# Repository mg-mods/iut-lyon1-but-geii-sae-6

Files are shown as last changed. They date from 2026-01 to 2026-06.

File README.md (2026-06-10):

# SAE 6 - Système d'alarme
Repo du projet **SAE 6 "système d'alarme"** réalisé dans le cadre de notre troisième année de BUT GEII à l'IUT Lyon 1.

## Concept initial
Notre projet consiste à développer un système d’alarme domestique complet, prêt à être installé sur une maison.

Les systèmes de surveillance actifs sont des détecteurs d’ouverture de portes et fenêtres ainsi qu’une caméra équipée de reconnaissance faciale à l’entrée.

L’interface utilisateur sera supportée par un M5Stack qui communiquera sans fil, en HF, avec le module central. À ce dernier sont reliés tous les différents composants (capteurs, reconnaissance faciale et alarme). L’interface permettra de verrouiller et déverrouiller le système d’alarme à l’aide d’un code à composer sur l’interface ou d’un badge RFID (à condition que la personne utilisant le badge soit reconnue par la reconnaissance faciale). Lorsqu’une intrusion est détectée, un module d’alarme est déclenché. 

Le module d'alimentation permet, en cas de coupure de courant, d'utiliser l'énergie stockée dans une batterie et de recharger cette dernière une fois le courant rétabli. Ce module d'alimentation est aussi responsable du déclenchement du mode dégradé permettant d'utiliser les modules critiques uniquement afin de réduire la consommation d'énergie. 

La communication étant critique, le système bascule en liaison BLE en cas de problème de communication en HF pour assurer une communication en permanence.

## Cahier des charges
### Cahier des charges initial :
- Détection d'ouverture d'une porte ou fenêtre
- Digicode pour déverrouiller l'alarme
- Reconnaissance faciale
- Alarme sonore
- Communication entre le digicode et la centrale en HF
- Protocole d'appairage entre le digicode et la centrale
- Détection d'erreur ou de signal anormal (sur les liaisons filaires)

### Améliorations possibles :
- Utilisation de badges RFID plutôt qu'un code, mais voir comment rendre cette solution sécurisée
- Communications en BLE si HF non fonctionnel
- Ajout d'une batterie et d'un mode dégradé en cas de coupure de courant
- Détecteur de mouvements
- Ajout d'un module GSM pour appeler le propriétaire et les forces de l'ordre ou un service de sécurité privée
- Ajout d'un bouton panique
- Empreinte biométrique

### Contraintes :
- Nécessité d'utiliser des capteurs à l'état haut par défaut pour détecter les failles
- Différenciation entre un capteur actif et un capteur absent ou endommagé

## Synoptique global initial
Au démarrage du projet, nous avions imaginé un fonctionnement bien précis pour notre système. Nous avons listé toutes les fonctionnalités que nous souhaitions implémenter et les avons reliées ensemble logiquement. L'ensemble du système tel que nous l'avions imaginé, sa décomposition en sous-systèmes et les interactions de ces derniers sont décrits ci-dessous :
[![](https://mermaid.ink/img/pako:eNqVVl1vokAU_SuTeWqz4opKUVKbtmhb0_oR6ma7G15GGJUUGDKMq67xv-8MCgysJa2JD3DuuWfu5dwLe-gQF0MDLnyycVaIMvBi2aEdAv5DPqLB7R7EKxRhAzgedXxcAz6aY98A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)](https://mermaid.live/edit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)

## Synoptique global final
À la fin du projet, certaines fonctionnalités n'ont pas pu être réalisées, que ce soit pour des raisons budgétaires ou que ces parties étaient trop chronophages. L'ensemble du système final, sa décomposition en sous-systèmes et les interactions de ces derniers sont décrits ci-dessous :
[![](https://mermaid.ink/img/pako:eNqNlV1v2jAUhv-K5atOI4x8AG1Upk6BtohRUGBaN-XGSQxETezIMYMO8d9nB0iclNEicZG87-NzfM6xs4MBDTG04SKmm2CFGAffXY94BIgfihFL7nYgW6EU2yCIWBDjBoiRj2Mb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)](https://mermaid.live/edit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)

## Organisation du repo
Chaque composant sera réparti dans des branches différentes de ce repo. Voici la liste des branches présentes :
- **main** : branche d'accueil du repo, laissée vide pour l'instant
- **alarm** : branche du module d'alarme (réalisée par Lilian CHARRIERE)
- **cmd** : branche du module de commande (ou "digicode", bien que cette appellation soit assez réductrice ; réalisée par Corentin DEBAISIEUX)
- **hf** : branche des transmissions HF et de la modulation du signal (réalisée par Gaspard DENIZOU)
- **hub** : branche du module principal (ou "hub" ; réalisée par Bastien PORTIER)
- **rasp** : branche du module de reconnaissance faciale (réalisée par Lilian CHARRIERE)

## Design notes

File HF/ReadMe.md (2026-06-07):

# Modulation haute fréquence

## Diagramme de fonctionnement théorique

| | Valeur |
| --- | --- |
| Signal UART | 9600 bps |
| Fréquence porteuse | 100 kHz |
| Fréquence d'émission | 13,56 MHz |
| Puissance d'émission | 10 dBm |

```mermaid
---
config:
  theme: forest
  themeVariables:
    lineColor: '#FFA100'

---

stateDiagram
  direction TB
  state modulation {
    direction TB
    Mi1 --> V1
    Ol1 --> PB1
    V1 --> PB2
    PB2 --> Me1 :Tension=100mVpp P = 14DBm
    PB1 --> Me1 :Tension =1 a 2 Vpp P = 4-10DBm
    Me1 --> [*]
    Mi1
    V1
    Ol1
    PB1
    PB2
    Me1
  }
  state Démodulation {
    direction TB
    [*] --> G
    G-->PD
    PD --> Me2
    Ol2 --> Me2
    Me2 --> PB3
    PB3 --> PLL
    PLL --> PB4
    PB4 -->trig
     trig -->Mi2
[*]    Me2
    Ol2
    PB3
    PLL
    Mi2
  }
  modulation --> Démodulation
  Mi1:Microcontrôleur
  V1:VCO
  Ol1:Oscillateur local 13 MHz
  PB1:Filtre passe-bas fc=13,56 MHz
  PB2:Filtre passe-bas Fc=100 kHz ordre 2
  Me1:Mélangeur
  Me2:Mélangeur
  Ol2:Oscillateur local 13 MHz
  PB3:Filtre passe-bande centré sur 100 kHz ordre 2
  PB4:Filtre passe-bas Fc=20 kHz ordre 2
  trig:Trigger de Schmitt
  PD:Pont de diodes
  G:Gain 10 dBm
```

Le gain de la partie démodulation se fait avec un AOP transimpédance si, à la sortie de l'antenne, on doit amplifier le signal.  
Le pont diviseur sert à bien avoir la bonne puissance en entrée du mélangeur.

## Simulation LTspice

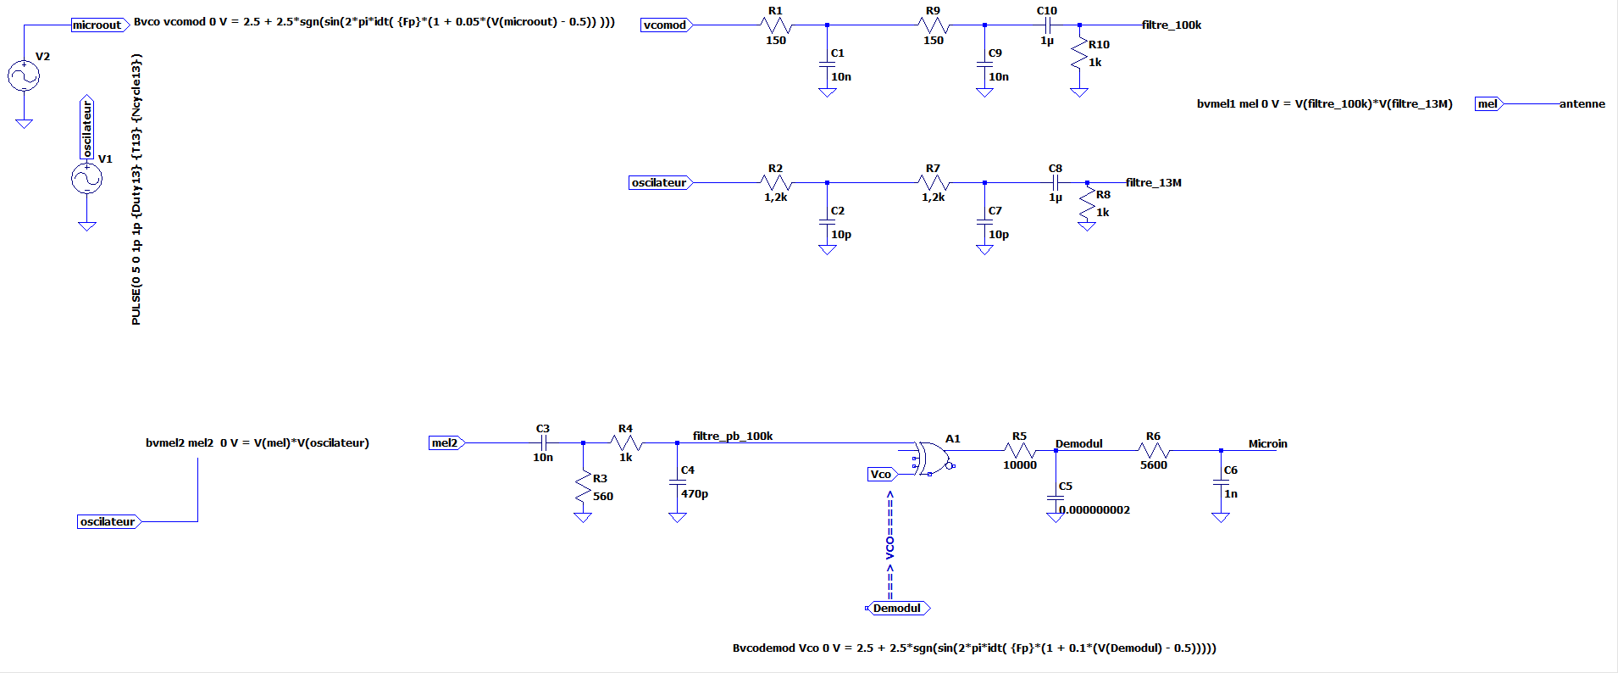
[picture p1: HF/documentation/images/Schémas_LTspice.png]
Capture d'écran schémas LTspice


Le VCO, la PLL et les mélangeurs n'étant pas répertoriés sur LTspice, ils sont simulés avec des lignes de commande.

| Composant | Ligne de commande |
| --- | --- |
| VCO modulation | `Bvco vcomod 0 V = 2.5 + 2.5*sgn(sin(2*pi*idt( {Fp}*(1 + 0.05*(V(microout) - 0.5)) )))` |
| Mélangeur modulation | `bvmel1 mel 0 V = V(filtre_100k)*V(filtre_13M)` |
| VCO démodulation | `Bvcodemod Vco 0 V = 2.5 + 2.5*sgn(sin(2*pi*idt( {Fp}*(1 + 0.1*(V(Demodul) - 0.5)))))` |
| Mélangeur démodulation | `bvmel2 mel2 0 V = V(mel)*V(oscilateur)` |

### Paramètres de simulation

| Paramètre | Valeur |
| --- | --- |
| Tsim | 5 ms |
| F | 9600 Hz |
| F13 | 13 560 000 Hz |
| Fp | 100 000 Hz |

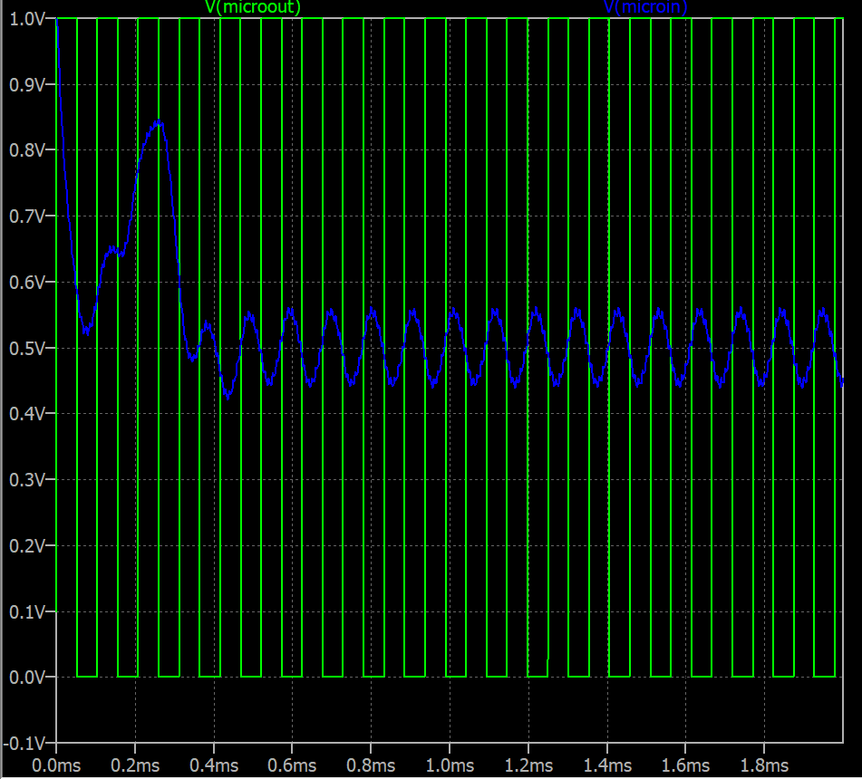
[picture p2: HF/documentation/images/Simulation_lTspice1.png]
Capture d'écran simulation LTspice 1


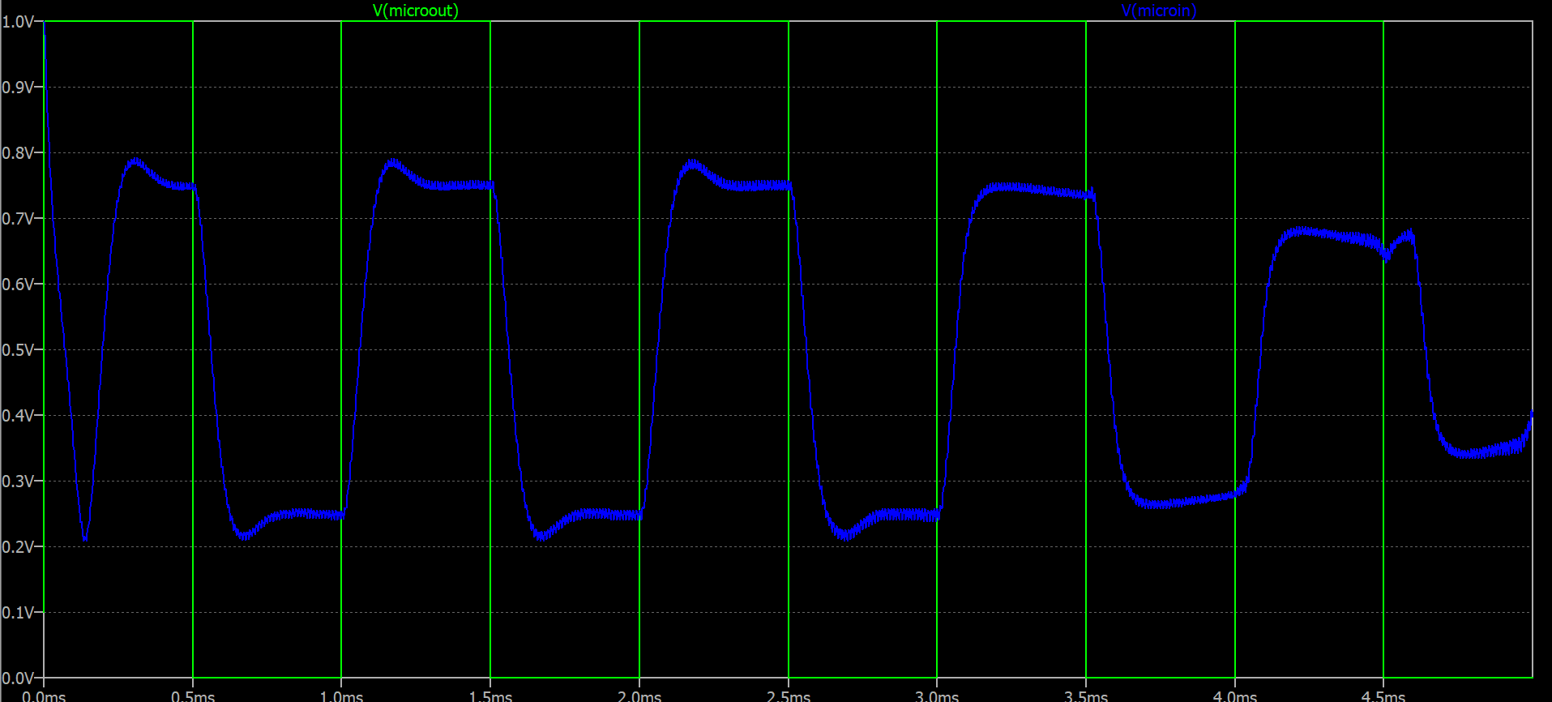
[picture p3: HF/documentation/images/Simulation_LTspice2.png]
Capture d'écran simulation LTspice 2


## Schémas KiCad théoriques

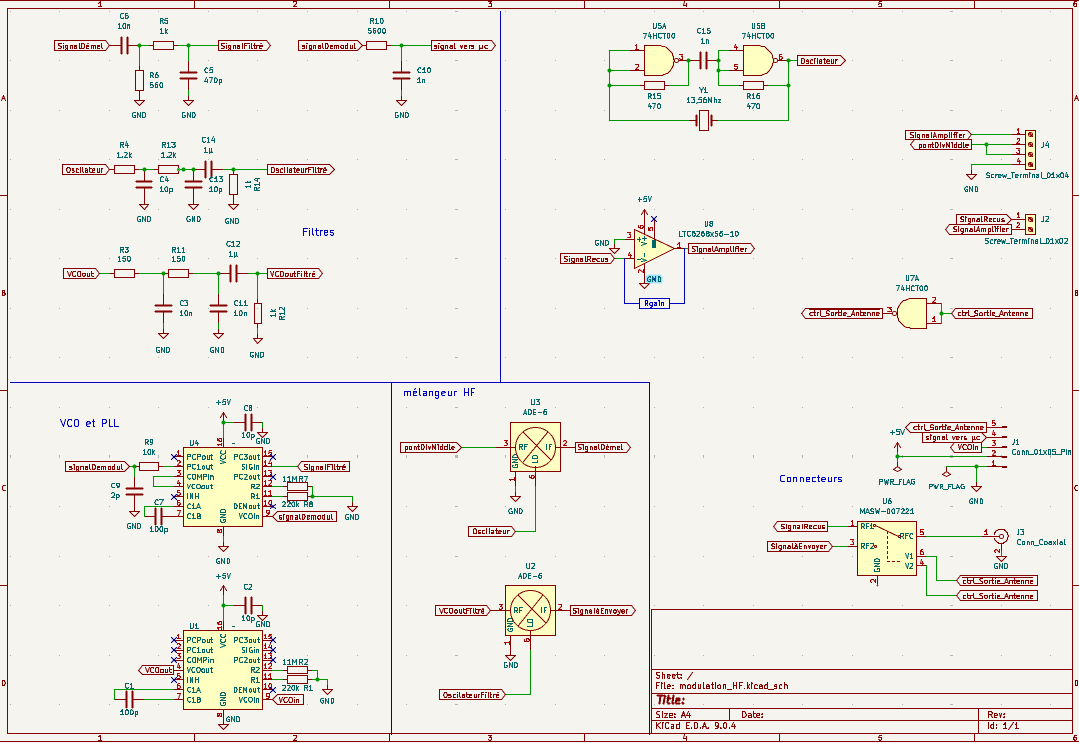
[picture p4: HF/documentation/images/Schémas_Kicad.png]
Schémas KiCad carte principale


L'adaptation d'impédance de l'antenne se fait sur une petite carte reliée par un câble BNC.

## Mise en pratique

Lors de la livraison des composants, nous n'avons pas reçu de 74HC4046 mais des CD4046BE. Bien que ce composant ait les mêmes fonctionnalités que le composant que nous avions choisi, son dimensionnement est bien différent pour les valeurs de résistance nécessaires.

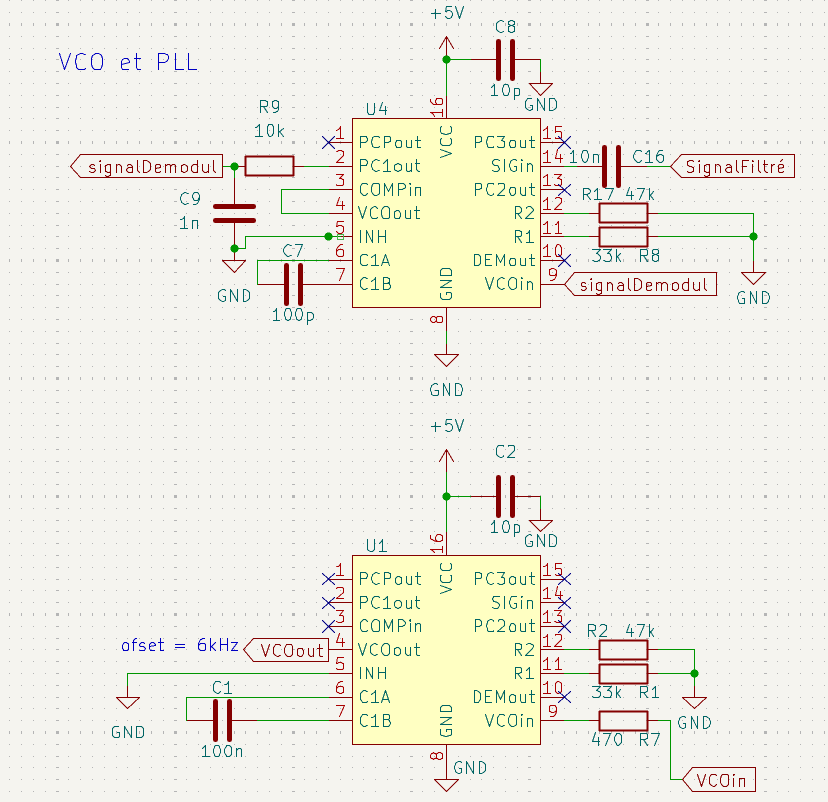
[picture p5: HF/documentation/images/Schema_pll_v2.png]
Schémas KiCad VCO et PLL deuxième version


Le VCO n'oscille plus à 100 kHz mais autour de 130 kHz. C'est entre autres dû à la datasheet du composant, qui n'est pas très lisible :

[lien datasheet CD4046BE](https://www.ti.com/lit/ds/symlink/cd4046b.pdf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)

## Travail réalisé

- [x] VCO et modulation à basse fréquence
- [x] PLL et démodulation à basse fréquence
- [ ] Utilisation du mélangeur pour basculer en haute fréquence
- [ ] Adaptation en impédance de l'antenne
- [ ] Utilisation du mélangeur pour basculer en basse fréquence

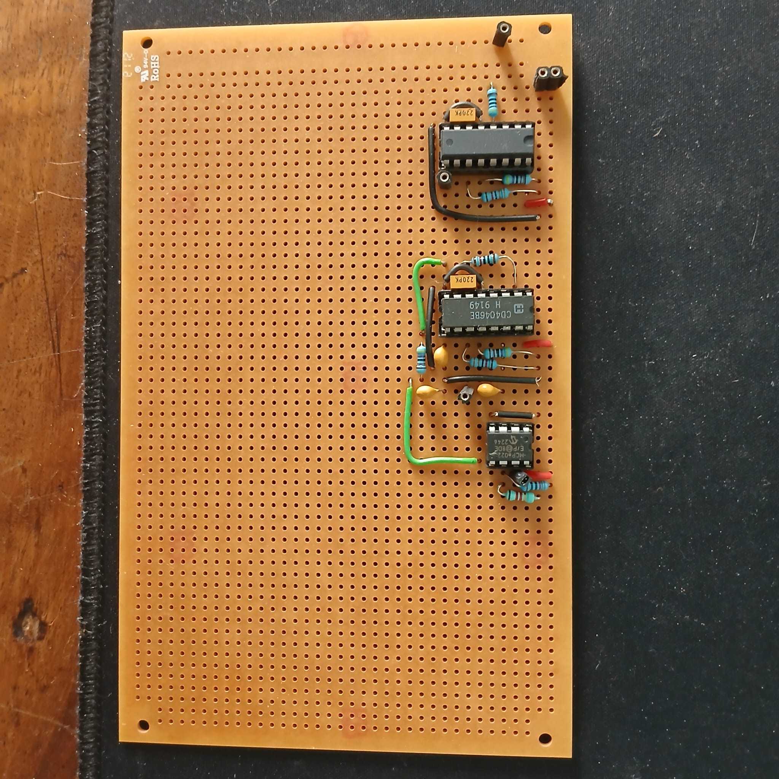
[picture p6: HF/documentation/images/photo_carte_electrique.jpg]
Photo de la carte électronique


## Test de bon fonctionnement

Pour vérifier le bon fonctionnement, j'ai effectué des mesures à l'oscilloscope en entrée et en sortie d'une liaison VCO-PLL avec, en entrée et en sortie, un microcontrôleur RP2040 choisi pour ses deux canaux UART et parce que les tensions de sortie UART correspondent aux microcontrôleurs utilisés dans notre système de surveillance (soit 3,3 V).

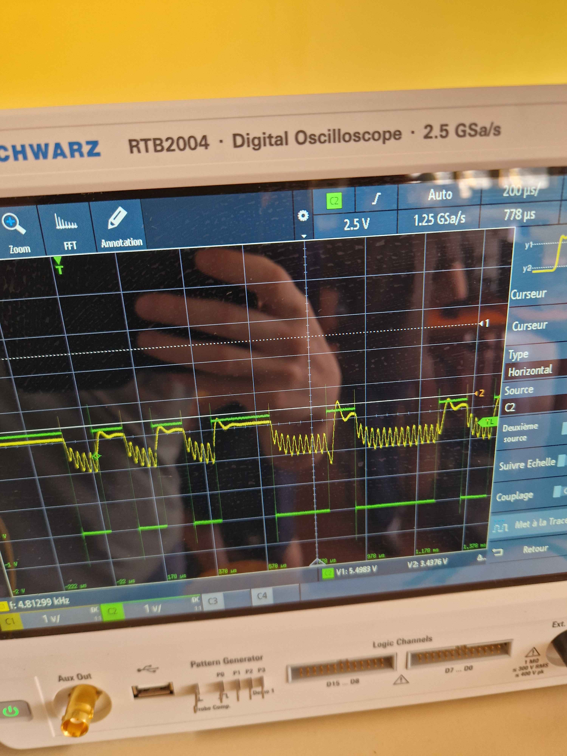
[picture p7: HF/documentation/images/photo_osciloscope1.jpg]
relevé oscilloscope en sortie de la PLL


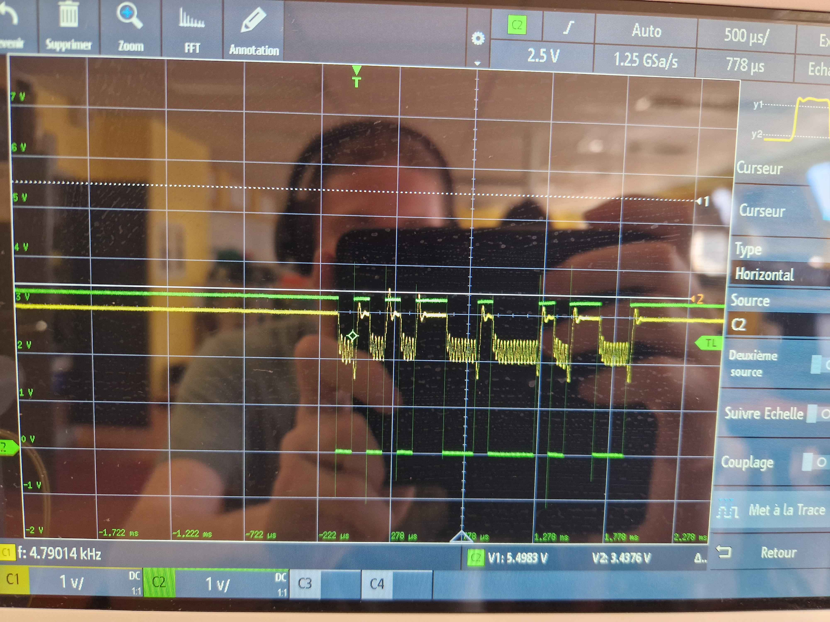
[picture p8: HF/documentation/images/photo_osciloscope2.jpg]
relevé oscilloscope en sortie de la PLL, après le filtre


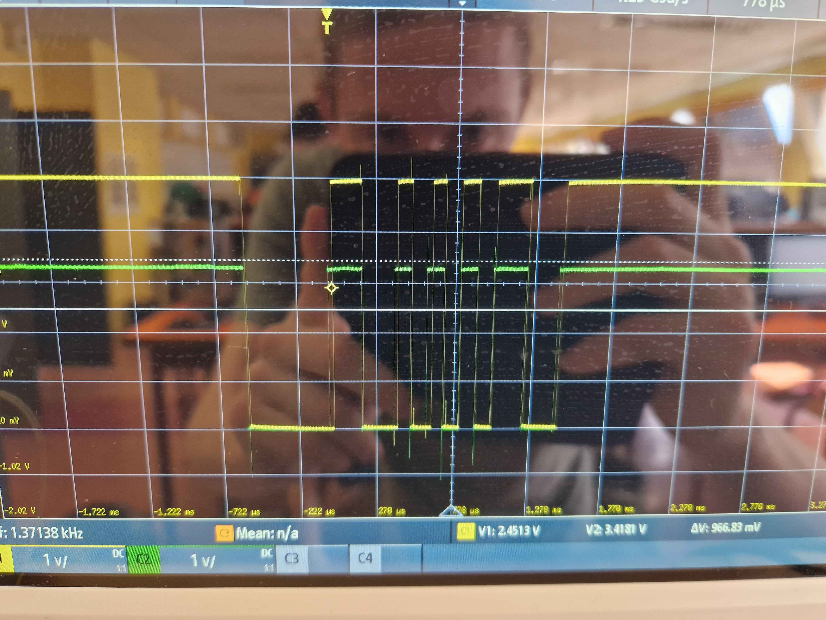
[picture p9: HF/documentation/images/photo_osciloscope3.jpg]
relevé oscilloscope en sortie de l'AOP


J'ai ensuite envoyé une série de 100 messages similaires à ceux qui sont envoyés entre le digicode et le hub, puis j'ai comparé le message d'origine avec le message reçu.

J'ai au maximum 10 messages reçus avec une erreur ou plus, soit 10 % d'erreur maximale de transmission en basse fréquence.

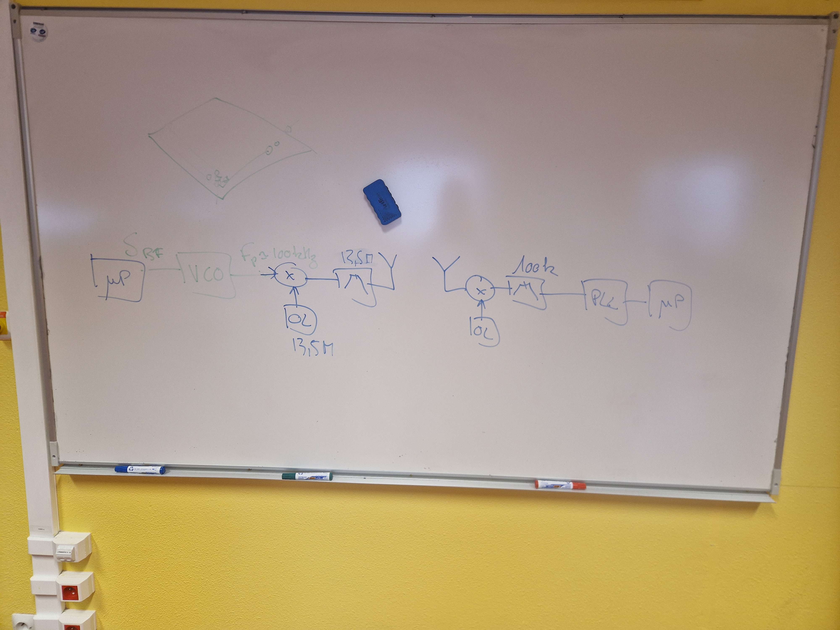
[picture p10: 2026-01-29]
HF/documentation/images/shcémas block modul.jpg

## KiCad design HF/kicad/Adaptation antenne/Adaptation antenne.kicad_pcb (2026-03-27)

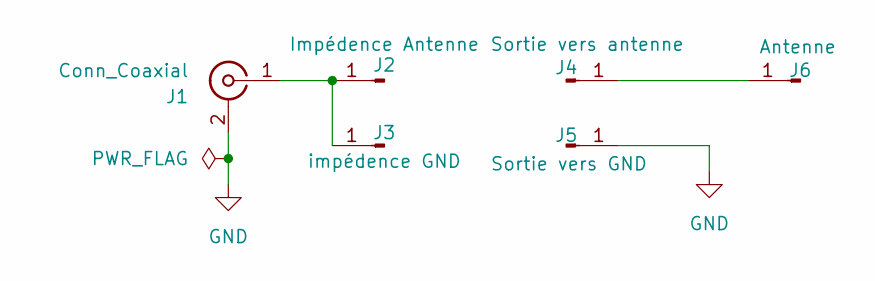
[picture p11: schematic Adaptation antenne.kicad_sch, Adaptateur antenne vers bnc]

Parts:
J1: Conn_Coaxial; Adaptateur BNC
J2: Impédence Antenne; PinHeader_1x01_P1.00mm_Vertical
J3: impédence GND; PinHeader_1x01_P1.00mm_Vertical
J4: Sortie vers antenne; PinHeader_1x01_P1.00mm_Vertical
J5: Sortie vers GND; PinHeader_1x01_P1.00mm_Vertical
J6: Antenne; PinHeader_1x01_P1.00mm_Vertical

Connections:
GND: J1.2 (Ext), J5.1
unnamed: J1.1 (In), J2.1, J3.1
unnamed: J4.1, J6.1

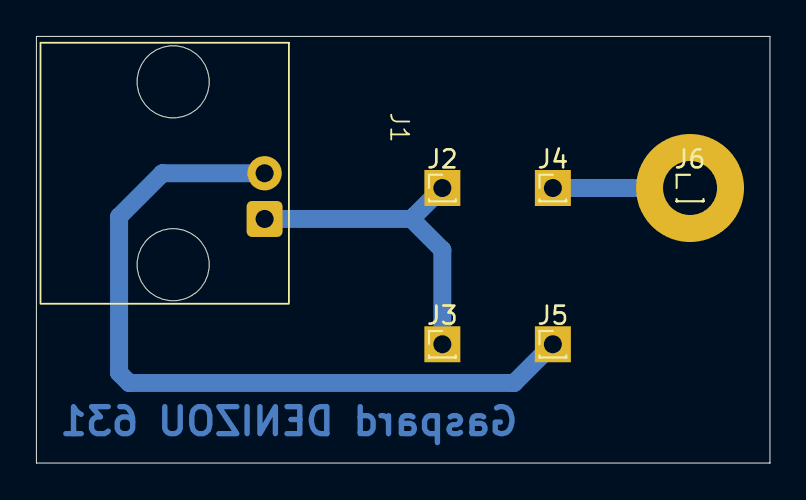
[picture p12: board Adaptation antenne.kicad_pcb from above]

Board: 2 copper layers, 40.8 x 23.7 mm, 6 parts (0 on the bottom side), 3 nets.

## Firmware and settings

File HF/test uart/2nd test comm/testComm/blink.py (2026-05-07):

from machine import Pin,UART
from utime import sleep_ms

pin = Pin("LED", Pin.OUT)


def lectureReception ():
    print(rec.read())


print("LED starts flashing...")
Tx = Pin(12)
comm = UART(0,9600)
comm.init(9600,bits=8,parity=None,tx=Tx)
rec = UART(1,9600)
rec.init(9600,bits=8,parity=None,rx = Pin(9))

while True:
    comm.write(b'54')
    rec.irq(lectureReception(),rec.IRQ_RXIDLE)
    sleep_ms(50)

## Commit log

2026-01-23 simu de la modulation et démodulation à 100k de porteuse
2026-01-29 changement theme de mermaid
2026-01-29 réparation des pb du schémas
2026-01-29 ajout d'une page de simulation pour les filtre du bloc de modulation et mélangeur
2026-02-07 modif graphique readme , ajout detail filtre et tension
2026-02-24 schémas de simulation de la liaison hf finit
2026-03-03 filtre en ordre 2+ passage en alternatif+ ajout sur kicad + ajout kicad interrupteur pour piloter l'entré/ sortie de l'antenne. manque plus que le gain en sortie du mélangeure
    [modulation_HF.kicad_sch]
2026-03-26 ajout carte adaptation pr antenne + comparateur pour sortie demodulation
    [Adaptation antenne.kicad_pcb, Adaptation antenne.kicad_sch, modulation_HF.kicad_sch]
2026-03-26 modif schémas de simulation
2026-03-27 modif kicad pour ajusté au test sur platin
    [Adaptation antenne.kicad_pcb, Adaptation antenne.kicad_sch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]
2026-05-07 modification pour incorporer une image
    [modulation_HF.kicad_sch]
2026-06-06 correction liens des images
2026-06-06 mise a jours schemas kicad
    [modulation_HF.kicad_sch]
